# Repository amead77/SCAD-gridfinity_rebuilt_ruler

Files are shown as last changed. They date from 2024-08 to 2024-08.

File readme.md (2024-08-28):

### This is a simple and customisable ruler holder for gridfinity in a 3x1 format.

Before I created this, I downloaded and printed: https://www.printables.com/model/841649-ruler-crib-gridfinity

which is shown in my pics. My model is maked ‘this model’. Now, I liked the model and I liked that the f3d file was included. But after printing I noticed the back of the ruler holder overhangs the base. For many people I guess this isn't an issue, but I wasn't keen on it and decided to edit the f3d file. Which is where I ran into an issue… it wasn't a simple case of new sketch on the side, then extrusion cut the top off and make my own. Nope, fusion threw an error when trying that. So I went on here and found a customisable blank: https://www.printables.com/model/498675-gridfinity-parametric-box-blank-fusion-360

Excellent, I thought…. and ran straight into Autodesks f.u to hobbyists. No longer can you use the customiser under a hobby licence. The moving goalposts is the reason I stopped using fusion in the first place. Plus I'm a forklift operator, how much money for a subscription do they think I have heh. Anyway….. 

Instead I went to kennetek's gridfinity-rebuilt: https://kennetek.github.io/gridfinity-rebuilt-openscad/

and used that as a basis, by creating a box, then removing everything I didn't need until I had a base. After that I created the 4 slanted parts and put them wholly within the grid area.

In total, it is a remix of kennetek's gridfinity boxes, while being inspired by akak's ruler holder.

there are some mistakes in the code, but it worked and I got the 
design I wanted out of it ;)

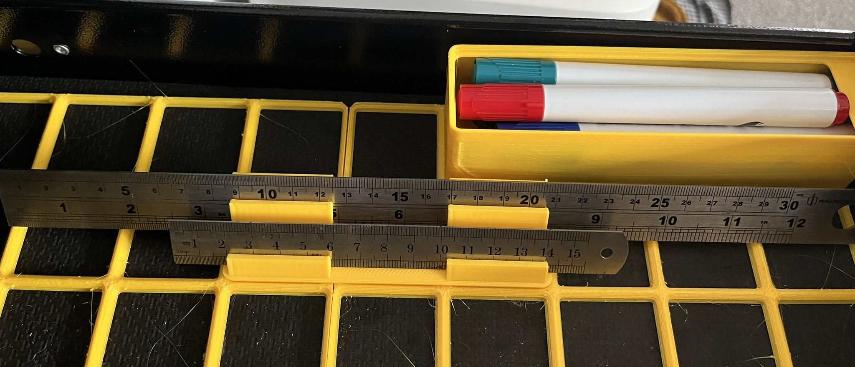
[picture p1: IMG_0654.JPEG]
my printed model


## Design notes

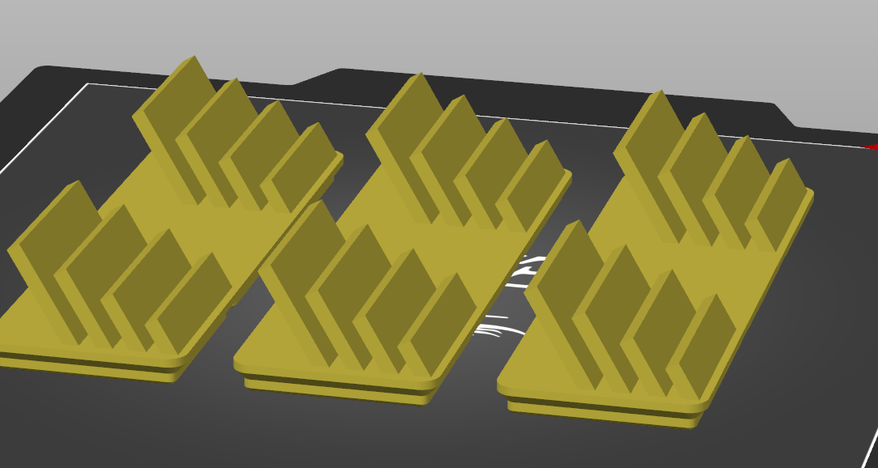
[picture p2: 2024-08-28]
Screenshot 2024-08-28 131225.png

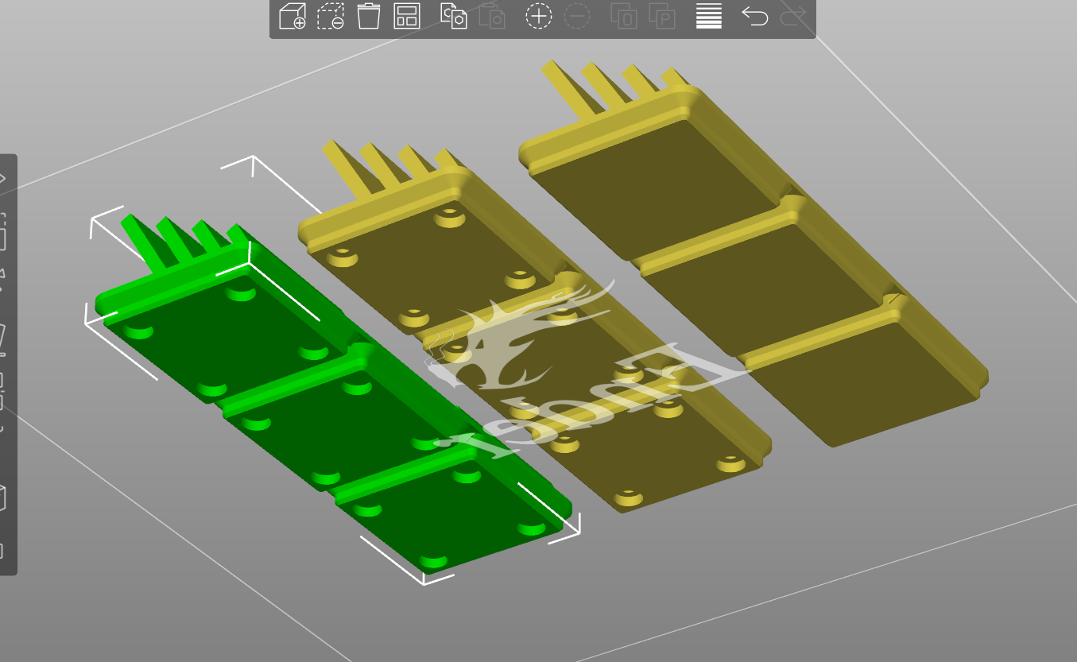
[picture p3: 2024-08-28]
Screenshot 2024-08-28 131149.png

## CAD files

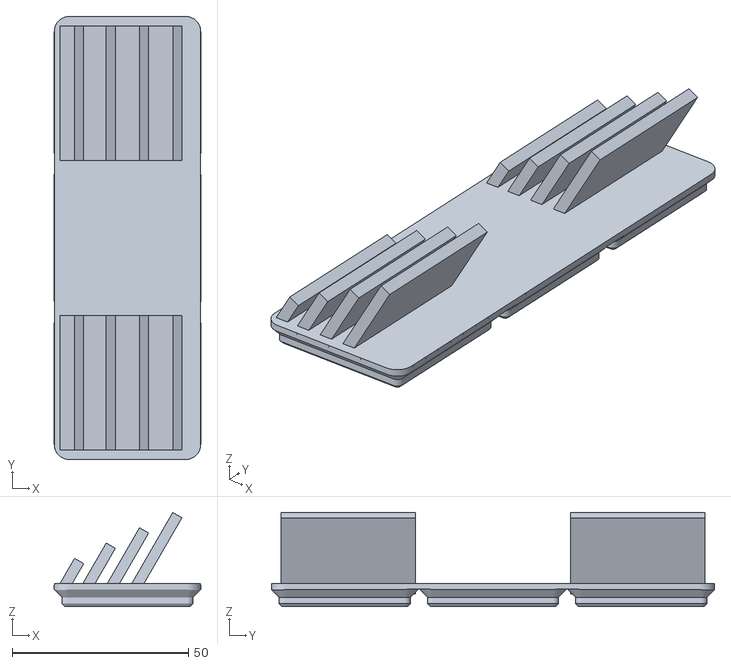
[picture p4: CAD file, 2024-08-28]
gridfintity_rule_flat.stl
41.5 x 125.5 x 26.7

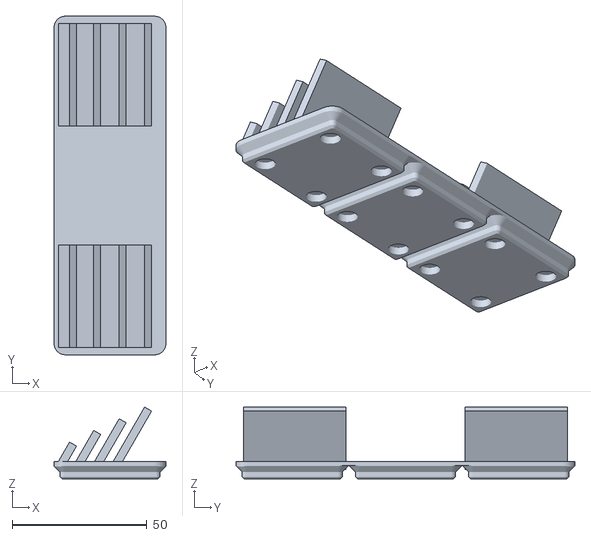
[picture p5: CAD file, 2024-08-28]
gridfintity_rule_mag_holes.stl
41.5 x 125.5 x 26.7

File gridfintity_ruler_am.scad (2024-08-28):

include <d:\Portableapps\Files\Programming\SCAD-gridfinity_rebuilt\gridfinity-rebuilt-utility.scad>
//it needs gridfinity-rebuilt to work, this is available on printables.com
//easiest way to test is to download the above, then dump this in the same folder and open it in OpenSCAD
$fa = 8;
$fs = 0.25;

//how many grids in the x, y direction
gridx = 1;
gridy = 3;

gridz = 0;// leave
length = 42; //leave, unless you're using a non standard grid
style_lip = 1; //does nothing right now

//change these to change the angle of the rows
cBackAngle = 30; 

//does nothing, because I made an oopsie
cBackLen = 2; //can you spot what I did ;) <hint... it was supposed to set the gap, instead the gap is defined by the thickness of the slanted parts

//thickness of the slanted parts
cBaseThick = 3;

//change these to change the height of the rows
cRow1height = 10;
cRow2height = 15;
cRow3height = 20;
cRow4height = 25;

//0 for flat bottom, 1 for mag holes, 2 for screw holes, which don't actually go right through, I was thinking it was for heat inserts, but then realised that wouldn't work
cHoles = 2;



function aoffset(ang, reqlen) = 
    reqlen / cos(ang);

module baseplate() {
    // Builds the base plate, this part is taken 99.9% from gridfinity-rebuilt, I just reused the code
    difference() {
        union () {
            gridfinityInit(gridx, gridy, height(gridz), 0, length) {

            };
            gridfinityBase(gridx, gridy, length, 1, 1, cHoles);
        };
    };
};


module slanted_cubes() {
//row 1 (front row first)
//    translate([aoffset(30, cBaseThick), 0, 0]) {
        rotate(a=30, v=[0, 1, 0]) {
            cube([cBaseThick, (length)-4, cRow1height]);
        };
//    }
//row 2
    translate([aoffset(30, cBaseThick) + cBaseThick, 0, 0]) {
        rotate(a=30, v=[0, 1, 0]) {
            cube([cBaseThick, (length)-4, cRow2height]);
        };
    };
//row 3
    translate([aoffset(30, cBaseThick*3) + cBaseThick, 0, 0]) {
        rotate(a=30, v=[0, 1, 0]) {
            cube([cBaseThick, (length)-4, cRow3height]);
        };
    };
//row 4
    translate([aoffset(30, cBaseThick*5) + cBaseThick, 0, 0]) {
        rotate(a=30, v=[0, 1, 0]) {
            cube([cBaseThick, (length)-4, cRow4height]);
        };
    };

};

module main() {
    baseplate();
    translate([-20, -60, 5]) {
        slanted_cubes();
    };
    translate([-20, 22, 5]) {
        slanted_cubes();
    };
}

main();

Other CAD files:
gridfintity_rule_screw.stl
